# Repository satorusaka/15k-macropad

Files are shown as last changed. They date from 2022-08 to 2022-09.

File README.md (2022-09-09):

# SKMT_15k_Macropad

A diy, 3d-printed, 15 key (3x5), hotswap, RGB macropad.

This repo contains gerber files for PCB, the 3D-printed parts and the QMK firmware for RPi Pico.

skmt_15k_macropad
[more images](https://imgur.com/a/5BjqMy4)

## Parts Required

- JLCPCB parts:
  - 1x skmt_15k Main Matrix
    - Get stencil to smd solder the components or pay for smd assembly services.
  - 1x skmt_15k Raspberry Pi sub-board
  - 1x USB-C-Breakout board
- SMD parts:
  - 15x 1N4148W SOD-123 Switching Diode
  - 15x sk6812mini-e RGB LED
  - 15x 100nF 0603 Multilayer Ceramic Capacitors
  - 15x kailh hotswap sockets
- THT parts:
  - 1x pin header 1x11p
- Fasterners:
  - 2x M3x12 screws (case)
  - 2x M2.5x4 screws (usb breakout)
  - 4x M2x6 screws (PCB)
- 3D printed parts:
  - 1x Top case
  - 1x Bottom case
  - 1x Plate
  - 4x m2 standoff
- 1x Raspberry Pi Pico
- 15x Keycaps
- 15x Switches

## Assembly Instructions

TO BE ADDED

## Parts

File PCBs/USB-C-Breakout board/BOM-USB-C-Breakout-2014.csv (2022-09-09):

Comment | Designator | Footprint | LCSC
5.1k | R1,R2 | R_0805_2012Metric_Pad1.20x1.40mm_HandSolder | C27834
USB_C_Receptacle_USB2.0 | J1 | USB_C_Receptacle_XKB_U262-16XN-4BVC11 | C319148
MountingHole_Pad | H1 | MountingHole_2.7mm_M2.5_ISO7380_Pad
MountingHole_Pad | H2 | MountingHole_2.7mm_M2.5_ISO7380_Pad
Conn_01x06 | J2 | PinHeader_1x06_P2.54mm_Vertical

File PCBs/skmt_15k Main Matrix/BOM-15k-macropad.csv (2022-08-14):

Comment | Designator | Footprint | LCSC
D_Small | D1,D10,D11,D12,D13,D14,D15,D2,D3,D4,D5,D6,D7,D8,D9 | D_SOD-123 | C2099
0.1uF | C1,C10,C11,C12,C13,C14,C15,C2,C3,C4,C5,C6,C7,C8,C9 | C_0603_1608Metric | C30926

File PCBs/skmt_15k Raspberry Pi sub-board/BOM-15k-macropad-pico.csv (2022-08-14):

Comment | Designator | Footprint | LCSC
MountingHole | H1 | MountingHole_2.2mm_M2
MountingHole | H3 | MountingHole_2.2mm_M2
MountingHole | H2 | MountingHole_2.2mm_M2
MountingHole | H4 | MountingHole_2.2mm_M2
Pico | U1 | RPi_Pico_SMD_TH
Conn_01x11 | J1 | PinHeader_1x11_P2.54mm_Vertical
Conn_01x04 | J2 | PinHeader_1x04_P2.54mm_Horizontal

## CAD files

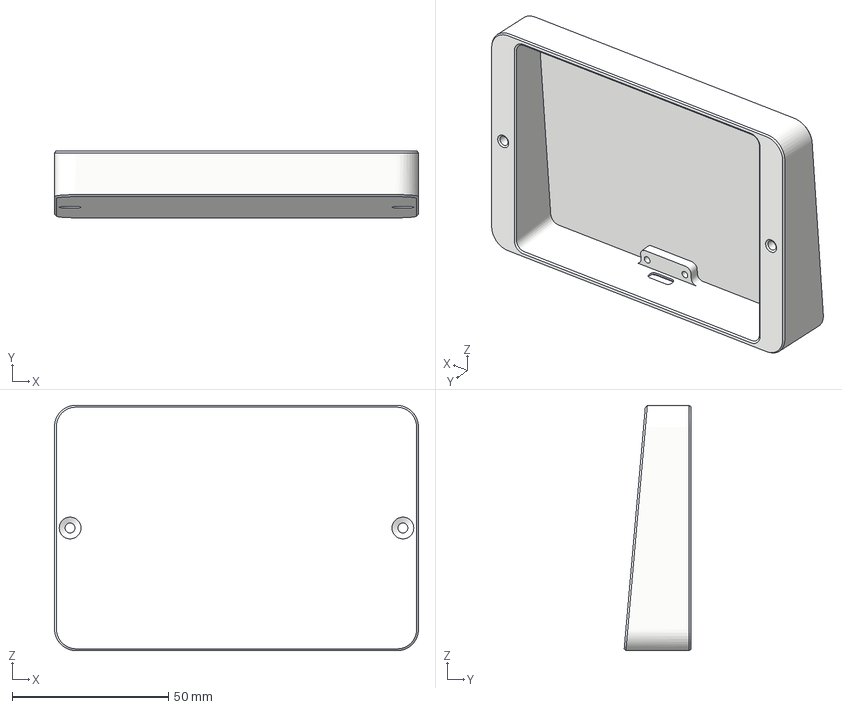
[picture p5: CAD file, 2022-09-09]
3d Printed parts/skmt-15k Bottom Case.3mf
116.6 x 21.3 x 78.6 mm

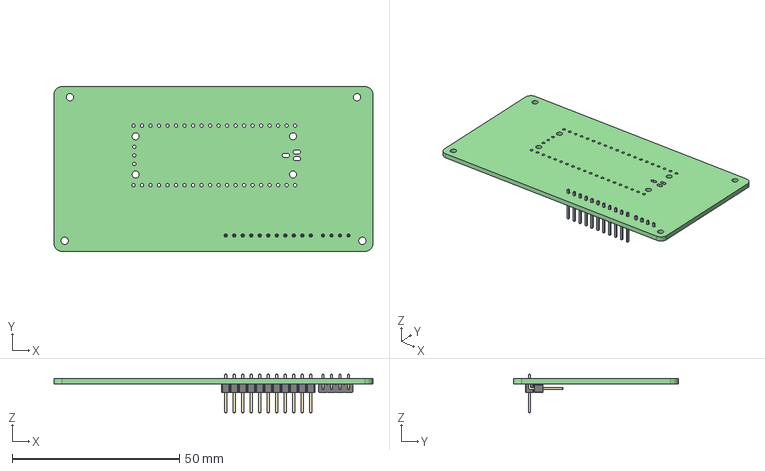
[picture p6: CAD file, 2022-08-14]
Source/15k-macropad/15k-macropad-pico/15k-macropad-pico.step
95.2 x 49.2 x 11.5 mm
_autosave-15k-macropad-pico PCB

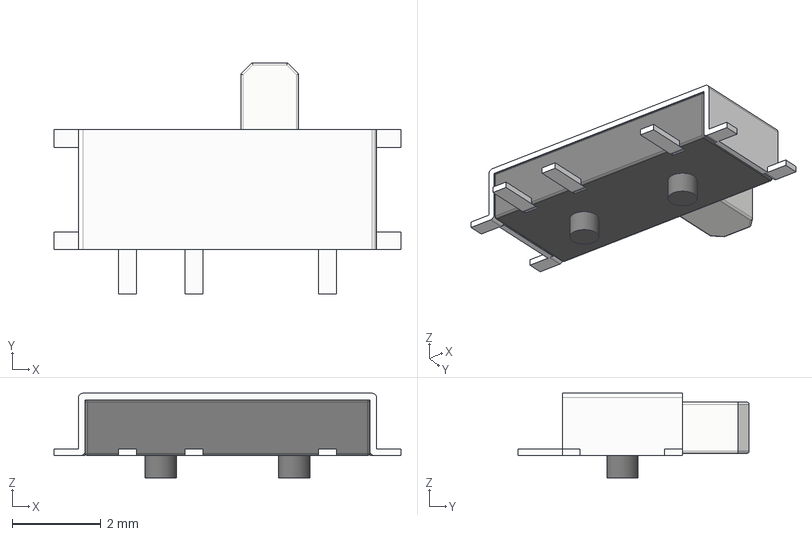
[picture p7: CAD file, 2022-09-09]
Source/marbastlib/3d/Switch_MSK12C02.step
7.80 x 5.20 x 1.90 mm

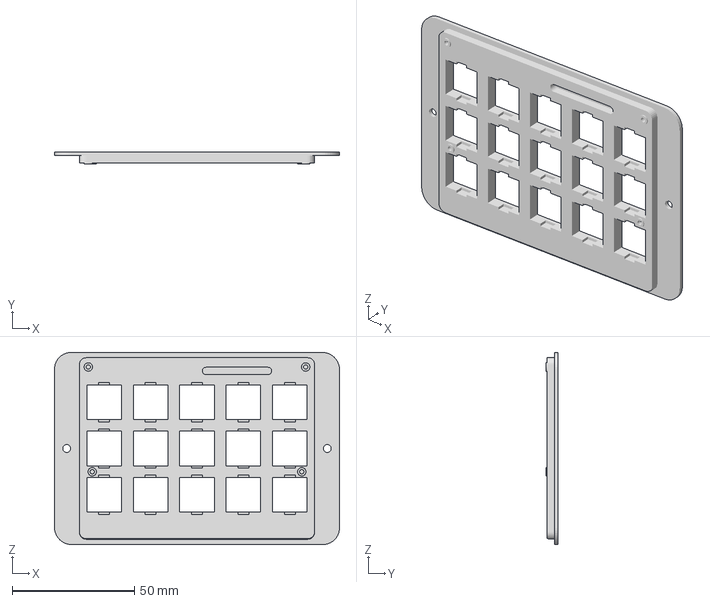
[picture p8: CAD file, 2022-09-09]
3d Printed parts/skmt-15k Plate.3mf
116.6 x 5.00 x 78.6 mm

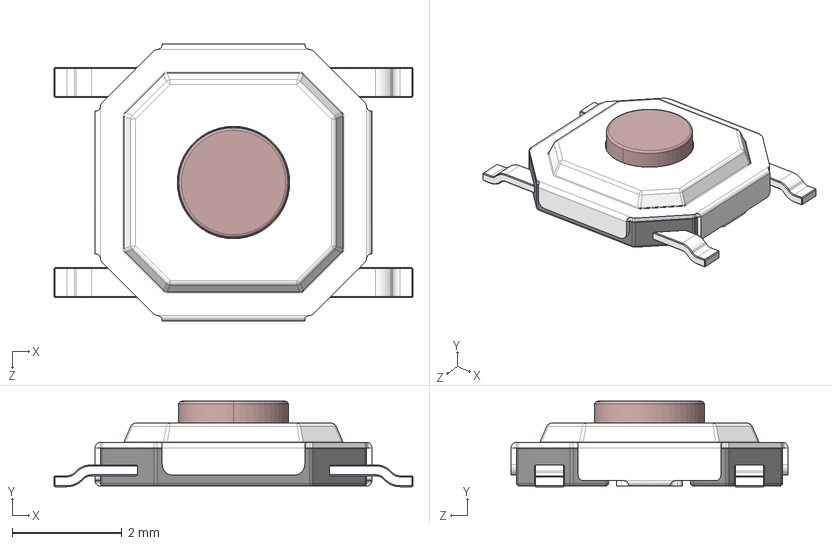
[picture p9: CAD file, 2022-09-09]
Source/marbastlib/3d/Switch_SKQG.step
6.55 x 1.56 x 5.05 mm
bottom part_ﾄｬﾈﾏｨｨ_
bottom pin_ﾄｬﾈﾏｨｨ_
top shield_ﾄｬﾈﾏｨｨ_
copper button_ﾄｬﾈﾏｨｨ_
shrapnel_默认è_

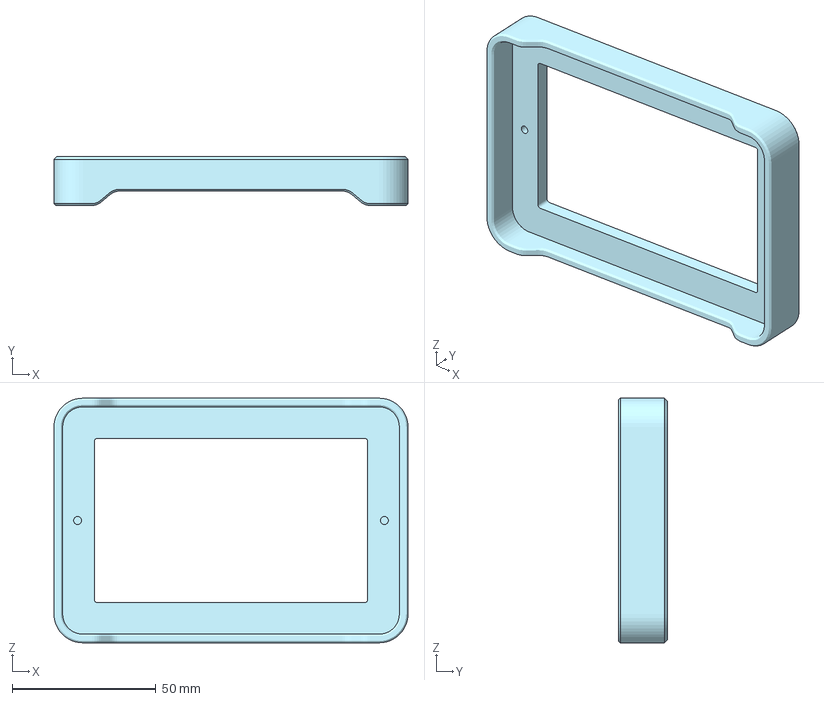
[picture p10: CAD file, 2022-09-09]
3d Printed parts/skmt-15k Top Case.3mf
123.0 x 17.0 x 85.0 mm

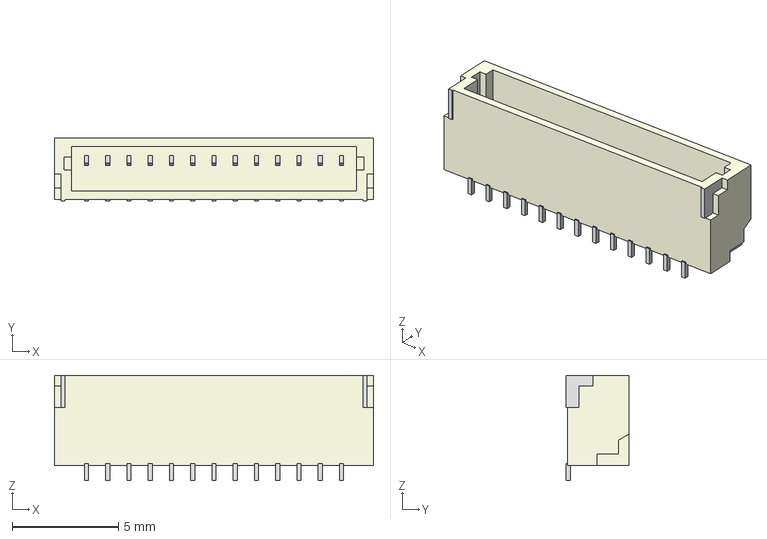
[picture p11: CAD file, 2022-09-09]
Source/marbastlib/3d/CON_SM13B-SRSS-TB.step
15.0 x 2.96 x 4.95 mm

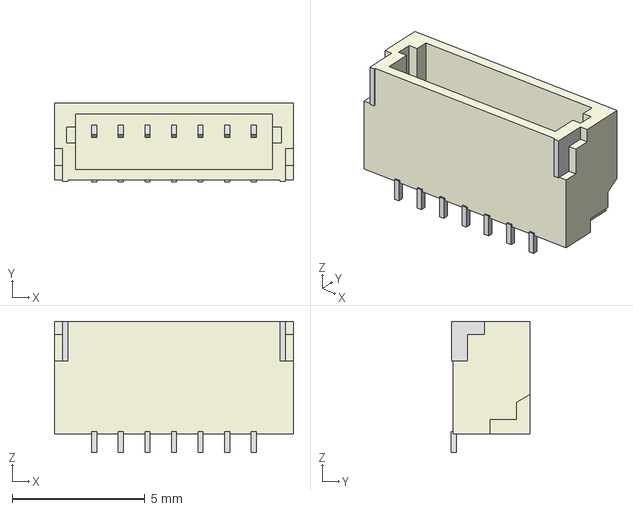
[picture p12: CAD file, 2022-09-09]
Source/marbastlib/3d/CON_SM07B-SRSS-TB.step
9.00 x 2.96 x 4.95 mm

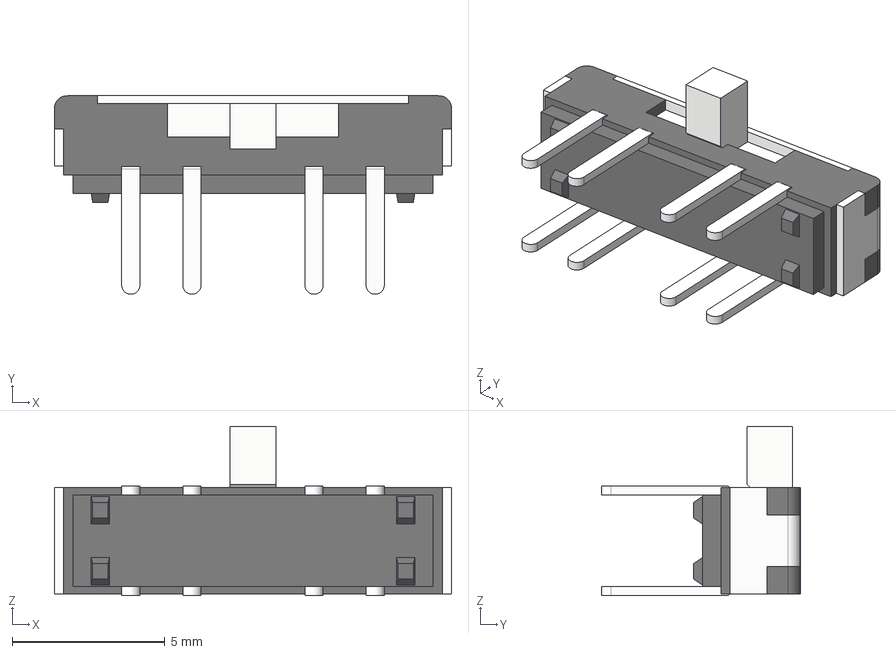
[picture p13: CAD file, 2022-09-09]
Source/marbastlib/3d/SW_SSSS223900.step
13.0 x 6.50 x 5.55 mm

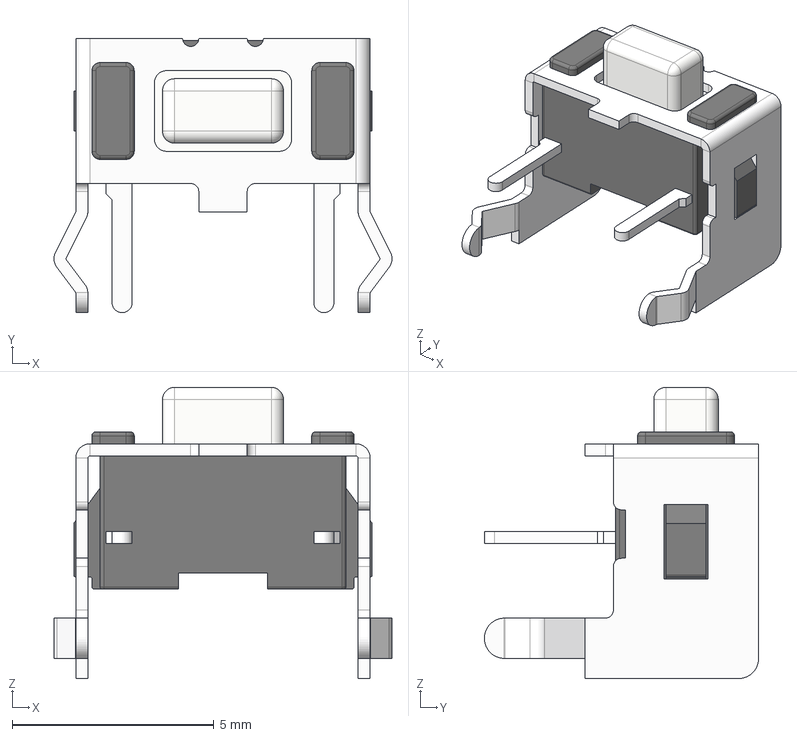
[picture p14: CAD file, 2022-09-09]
Source/marbastlib/3d/SW_SKHLLC.step
8.38 x 6.80 x 7.22 mm

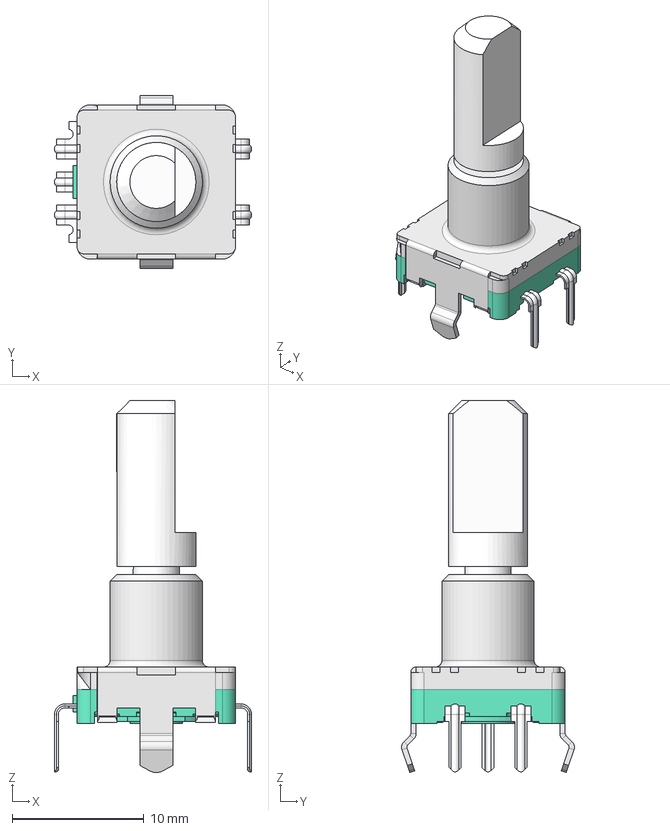
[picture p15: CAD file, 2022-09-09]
Source/marbastlib/3d/ROT_EC11E.step
14.9 x 13.1 x 28.2 mm

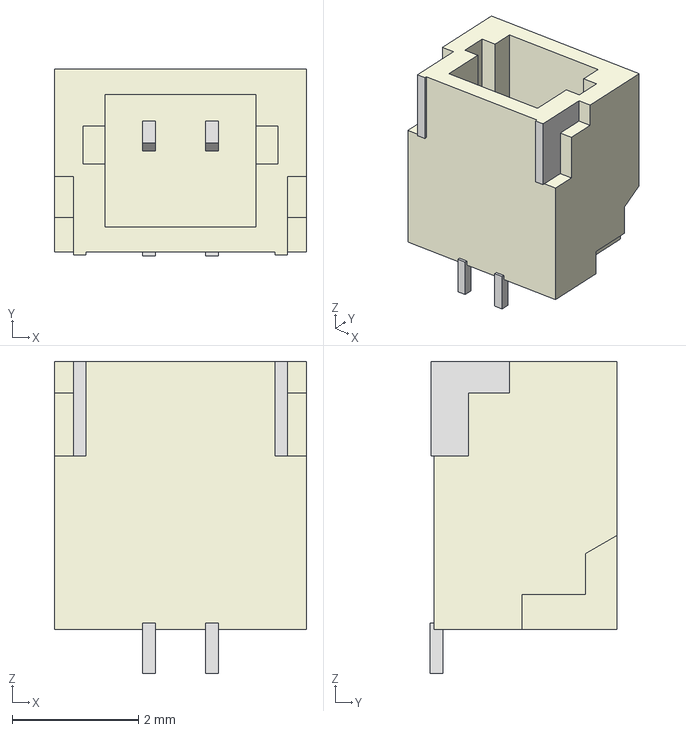
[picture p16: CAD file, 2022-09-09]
Source/marbastlib/3d/CON_SM02B-SRSS-TB.step
4.00 x 2.96 x 4.95 mm

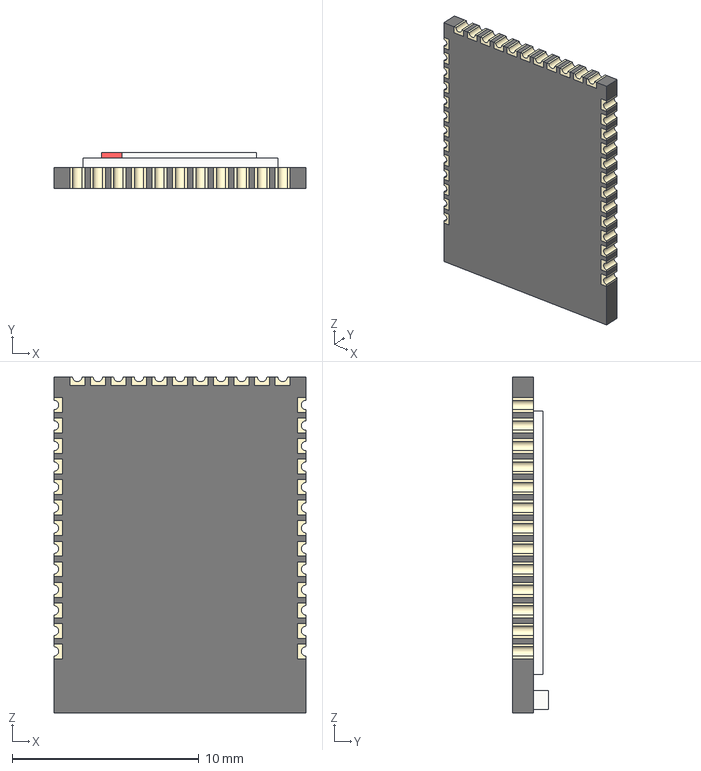
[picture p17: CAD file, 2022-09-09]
Source/marbastlib/3d/holyiot_18010_nRF52840.step
13.5 x 1.92 x 18.0 mm

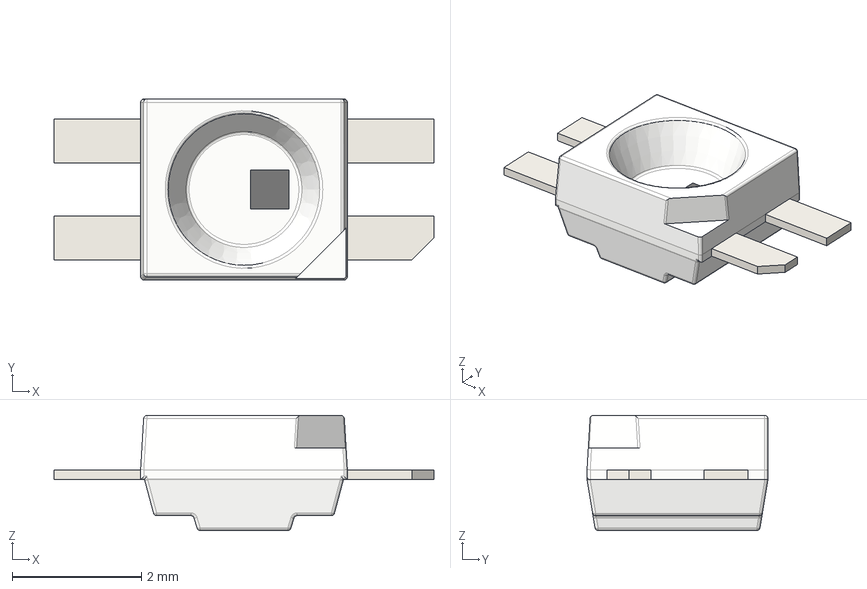
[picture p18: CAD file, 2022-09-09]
Source/marbastlib/3d/LED_SK6812MINI-E.step
5.88 x 2.80 x 1.78 mm

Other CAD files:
Source/marbastlib/3d/CON_TYPE-C-31-M-14.step
Source/marbastlib/3d/CON_SM06B-SRSS-TB.step
Source/marbastlib/3d/Switch_ESP3020.step
Source/marbastlib/3d/LED_WS2812_2020.step
3d Printed parts/m2x2.4 standoff.3mf
Source/marbastlib/3d/CON_MJ-4PP-9.step
Source/marbastlib/3d/CON_SM04B-SRSS-TB.step
Source/marbastlib/3d/CON_SM05B-SRSS-TB.step
Source/marbastlib/3d/CON_SM08B-SRSS-TB.step
Source/marbastlib/3d/CON_TYPE-C-31-M-12.step
Source/marbastlib/3d/Crystal_FA-128.step
Source/marbastlib/3d/HS_Kailh_Choc.step
Source/marbastlib/3d/HS_Kailh_MX.step
Source/marbastlib/3d/LED_WS2812B-MINI.step
Source/marbastlib/3d/MSK12C02.step
Source/marbastlib/3d/ROT_EC11N.step
Source/marbastlib/3d/SW_SSSS213100.step
Source/marbastlib/3d/joystick_psp1000.step

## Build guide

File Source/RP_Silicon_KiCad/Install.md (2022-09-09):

# Install KiCad libraries

## Manage Symbol Libraries

Accessed from the Preferences menu, add a new line with the +, give it a name and use the folder icon to point to the directory/folder where you have KiCadLibraries.

Manage Symbol Libraries screen shot


## Manage Footprint Libraries

Ditto! Accessed from the Preferences menu, add a new line with the +, give it a name and use the folder icon to point to the directory/folder where you have KiCadLibraries.

Manage Footprint Libraries screen shot


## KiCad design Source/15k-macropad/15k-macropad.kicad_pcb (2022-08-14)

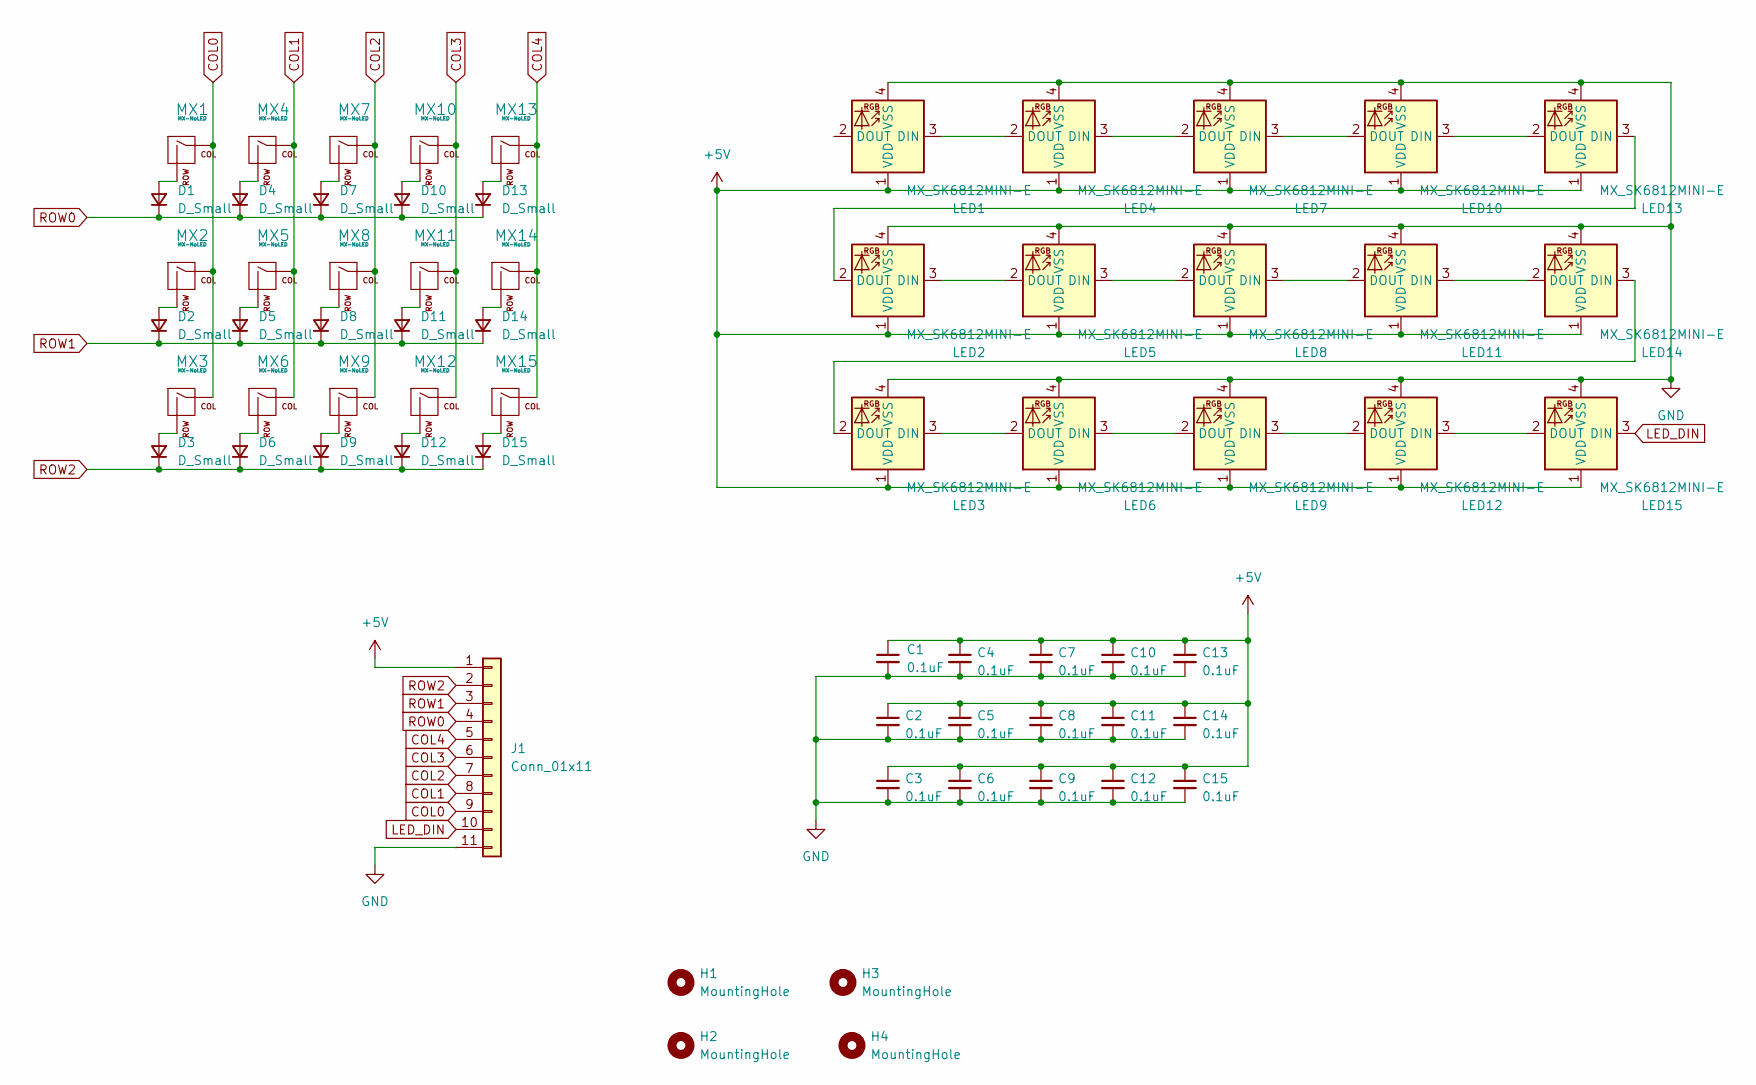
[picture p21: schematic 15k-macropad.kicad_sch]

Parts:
C1, C2, C3, C4, C5, C6, C7, C8, C9, C10, C11, C12, C13, C14, C15: 0.1uF; C_0603_1608Metric
D1, D2, D3, D4, D5, D6, D7, D8, D9, D10, D11, D12, D13, D14, D15: D_Small; D_SOD-123
H1, H2, H3, H4: MountingHole; MountingHole_2.2mm_M2
J1: Conn_01x11; PinHeader_1x11_P2.54mm_Vertical
LED1, LED2, LED3, LED4, LED5, LED6, LED7, LED8, LED9, LED10, LED11, LED12, LED13, LED14, LED15: MX_SK6812MINI-E; LED_MX_6028R
MX1, MX2, MX3, MX4, MX5, MX6, MX7, MX8, MX9, MX10, MX11, MX12, MX13, MX14, MX15: MX-NoLED; SW_Hotswap_Kailh_MX_1.00u

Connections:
+5V: C1.1, C2.1, C3.1, C4.1, C5.1, C6.1, C7.1, C8.1, C9.1, C10.1, C11.1, C12.1, C13.1, C14.1, C15.1, J1.1, LED1.1 (VDD), LED2.1 (VDD), LED3.1 (VDD), LED4.1 (VDD), LED5.1 (VDD), LED6.1 (VDD), LED7.1 (VDD), LED8.1 (VDD), LED9.1 (VDD), LED10.1 (VDD), LED11.1 (VDD), LED12.1 (VDD), LED13.1 (VDD), LED14.1 (VDD), LED15.1 (VDD)
COL0: J1.9, MX1.1 (COL), MX2.1 (COL), MX3.1 (COL)
COL1: J1.8, MX4.1 (COL), MX5.1 (COL), MX6.1 (COL)
COL2: J1.7, MX7.1 (COL), MX8.1 (COL), MX9.1 (COL)
COL3: J1.6, MX10.1 (COL), MX11.1 (COL), MX12.1 (COL)
COL4: J1.5, MX13.1 (COL), MX14.1 (COL), MX15.1 (COL)
GND: C1.2, C2.2, C3.2, C4.2, C5.2, C6.2, C7.2, C8.2, C9.2, C10.2, C11.2, C12.2, C13.2, C14.2, C15.2, J1.11, LED1.4 (VSS), LED2.4 (VSS), LED3.4 (VSS), LED4.4 (VSS), LED5.4 (VSS), LED6.4 (VSS), LED7.4 (VSS), LED8.4 (VSS), LED9.4 (VSS), LED10.4 (VSS), LED11.4 (VSS), LED12.4 (VSS), LED13.4 (VSS), LED14.4 (VSS), LED15.4 (VSS)
LED_DIN: J1.10, LED15.3 (DIN)
unnamed: D1.2 (A), MX1.2 (ROW)
unnamed: D2.2 (A), MX2.2 (ROW)
unnamed: D3.2 (A), MX3.2 (ROW)
unnamed: D4.2 (A), MX4.2 (ROW)
unnamed: D5.2 (A), MX5.2 (ROW)
unnamed: D6.2 (A), MX6.2 (ROW)
unnamed: D7.2 (A), MX7.2 (ROW)
unnamed: D8.2 (A), MX8.2 (ROW)
unnamed: D9.2 (A), MX9.2 (ROW)
unnamed: D10.2 (A), MX10.2 (ROW)
unnamed: D11.2 (A), MX11.2 (ROW)
unnamed: D12.2 (A), MX12.2 (ROW)
unnamed: D13.2 (A), MX13.2 (ROW)
unnamed: D14.2 (A), MX14.2 (ROW)
unnamed: D15.2 (A), MX15.2 (ROW)
unnamed: LED1.3 (DIN), LED4.2 (DOUT)
unnamed: LED2.3 (DIN), LED5.2 (DOUT)
unnamed: LED3.3 (DIN), LED6.2 (DOUT)
unnamed: LED4.3 (DIN), LED7.2 (DOUT)
unnamed: LED5.3 (DIN), LED8.2 (DOUT)
unnamed: LED6.3 (DIN), LED9.2 (DOUT)
unnamed: LED7.3 (DIN), LED10.2 (DOUT)
unnamed: LED10.3 (DIN), LED13.2 (DOUT)
unnamed: LED8.3 (DIN), LED11.2 (DOUT)
unnamed: LED11.3 (DIN), LED14.2 (DOUT)
unnamed: LED9.3 (DIN), LED12.2 (DOUT)
unnamed: LED12.3 (DIN), LED15.2 (DOUT)
unnamed: LED2.2 (DOUT), LED13.3 (DIN)
unnamed: LED3.2 (DOUT), LED14.3 (DIN)
ROW0: D1.1 (K), D4.1 (K), D7.1 (K), D10.1 (K), D13.1 (K), J1.4
ROW1: D2.1 (K), D5.1 (K), D8.1 (K), D11.1 (K), D14.1 (K), J1.3
ROW2: D3.1 (K), D6.1 (K), D9.1 (K), D12.1 (K), D15.1 (K), J1.2

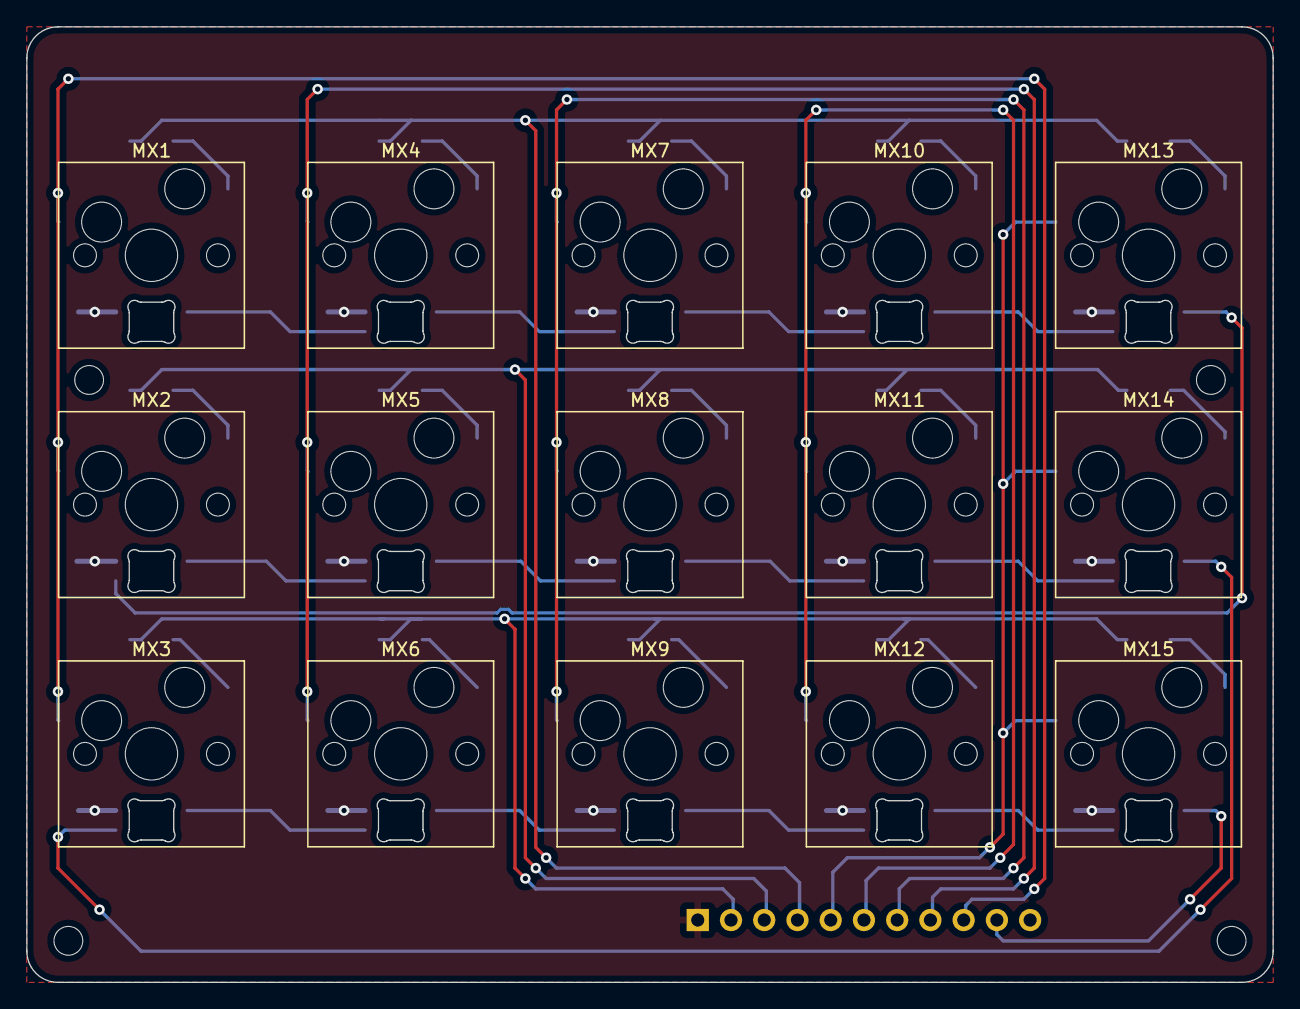
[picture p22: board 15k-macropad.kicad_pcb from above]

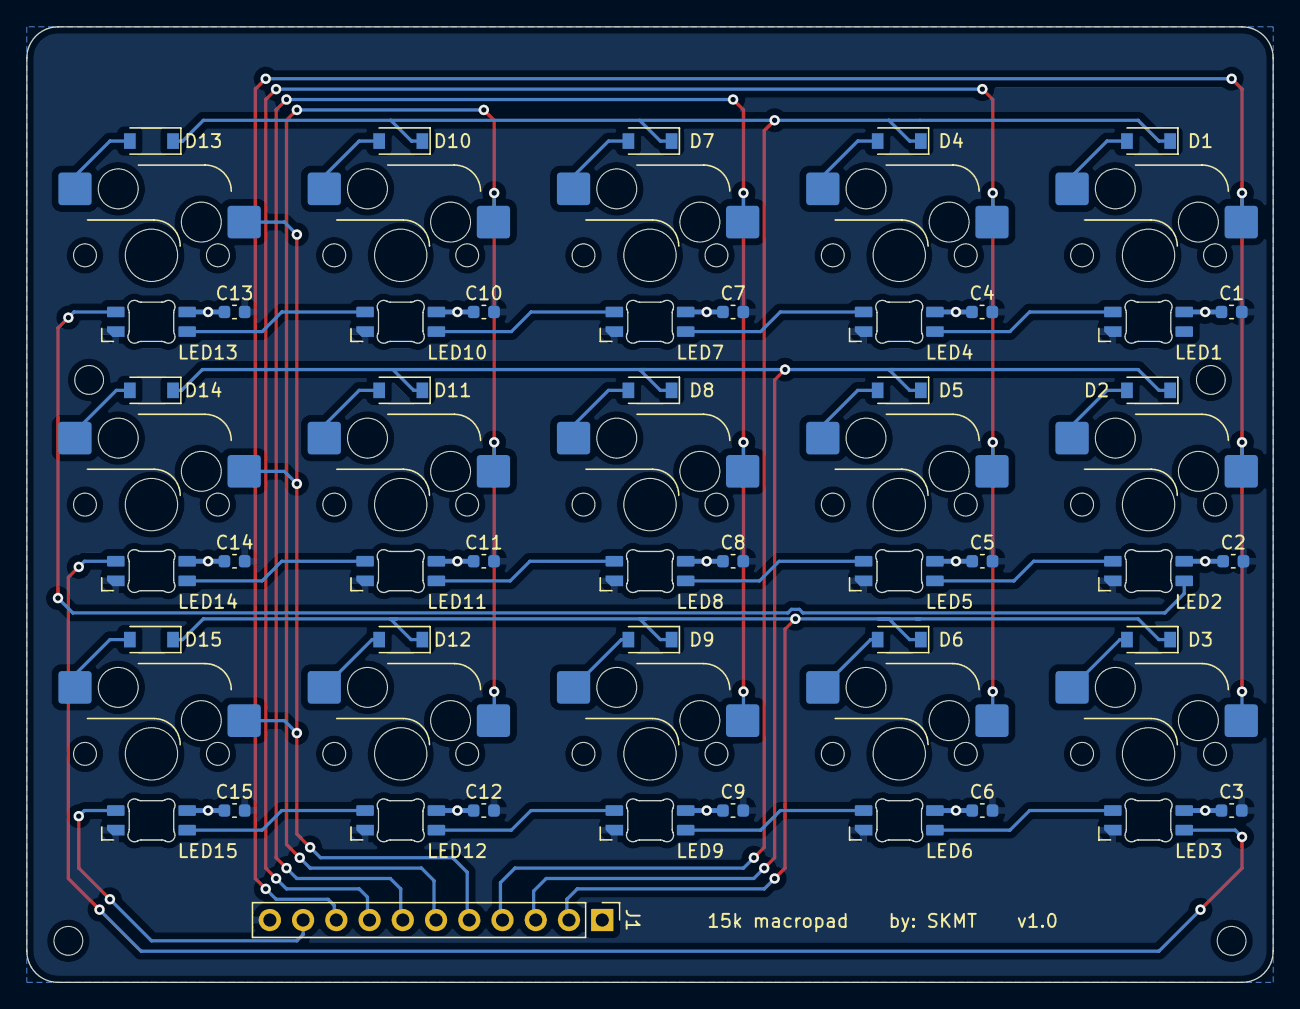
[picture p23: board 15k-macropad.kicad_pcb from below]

Board: 2 copper layers, 95.2 x 73.0 mm, 65 parts (46 on the bottom side), 40 nets.

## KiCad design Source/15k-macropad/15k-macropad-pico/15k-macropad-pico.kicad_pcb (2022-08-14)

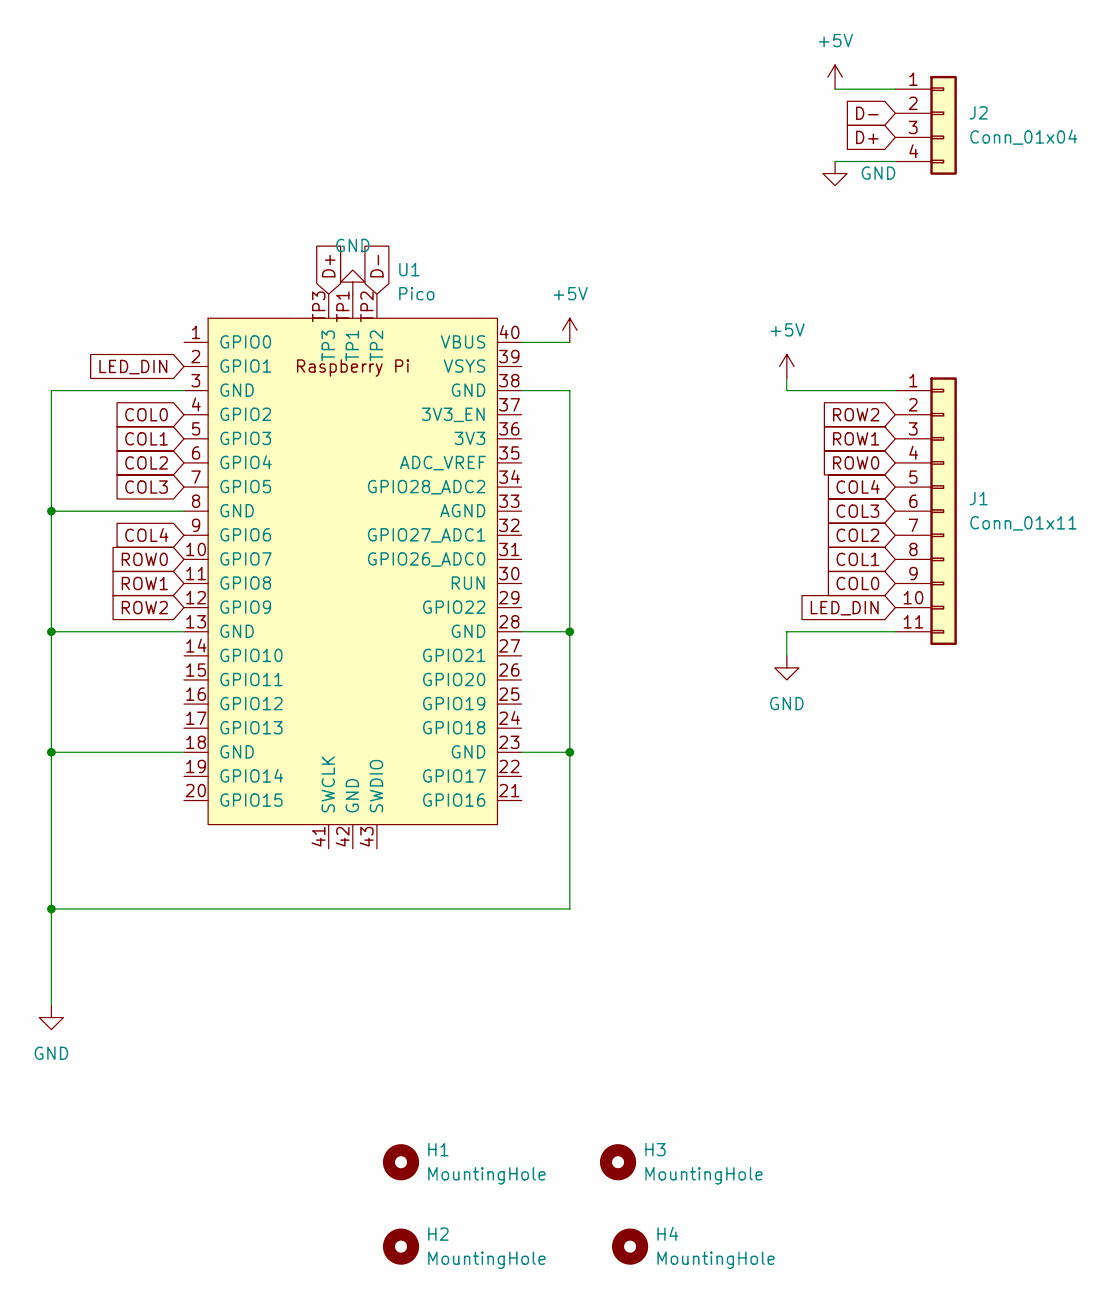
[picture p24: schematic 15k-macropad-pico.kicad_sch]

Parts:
H1, H2, H3, H4: MountingHole; MountingHole_2.2mm_M2
J1: Conn_01x11; PinHeader_1x11_P2.54mm_Vertical
J2: Conn_01x04; PinHeader_1x04_P2.54mm_Horizontal
U1: Pico; RPi_Pico_SMD_TH

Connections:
+5V: J1.1, J2.1, U1.40 (VBUS)
COL0: J1.9, U1.4 (GPIO2)
COL1: J1.8, U1.5 (GPIO3)
COL2: J1.7, U1.6 (GPIO4)
COL3: J1.6, U1.7 (GPIO5)
COL4: J1.5, U1.9 (GPIO6)
D+: J2.3, U1.TP3
D-: J2.2, U1.TP2
GND: J1.11, J2.4, U1.3 (GND), U1.8 (GND), U1.13 (GND), U1.18 (GND), U1.23 (GND), U1.28 (GND), U1.38 (GND), U1.TP1
LED_DIN: J1.10, U1.2 (GPIO1)
ROW0: J1.4, U1.10 (GPIO7)
ROW1: J1.3, U1.11 (GPIO8)
ROW2: J1.2, U1.12 (GPIO9)

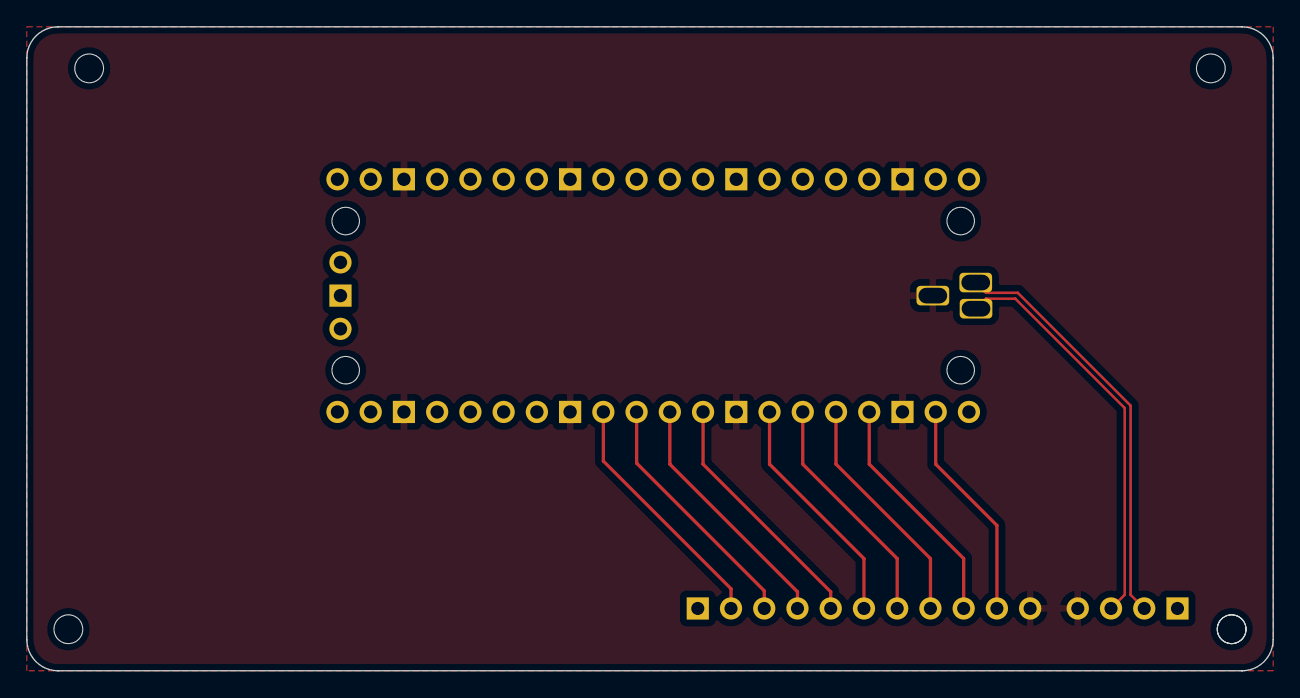
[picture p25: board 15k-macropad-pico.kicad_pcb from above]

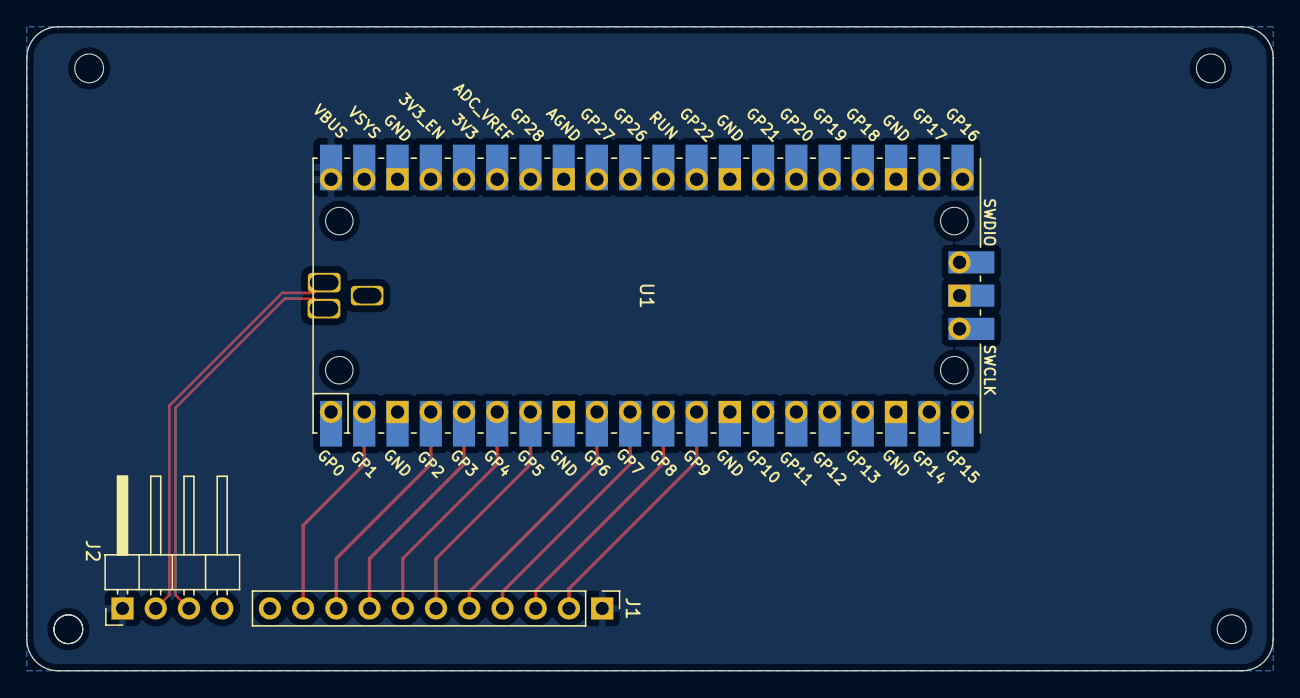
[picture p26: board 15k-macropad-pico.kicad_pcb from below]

Board: 2 copper layers, 95.2 x 49.2 mm, 8 parts (3 on the bottom side), 13 nets.

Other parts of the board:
H4#2: MountingHole; MountingHole_2.2mm_M2
